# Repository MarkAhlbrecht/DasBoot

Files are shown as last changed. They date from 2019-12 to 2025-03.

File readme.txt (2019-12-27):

This directory is for data files
File Descriptions
S2_long_static - Sense Hat 2 Long Run with no motion at 30 deg (temp is tag 7)
heading_cal_test - Level with compass cal circles while temp rises throught self heating
heading_cal_test2 - Continuation of above after crash
S2_RotCal_1217 - Sense Hat 2 Rot Cal
	 (30 deg increment level swing)
         (pitch -30 +45 +90 with 45 deg level swing)
 	 (roll -30 +45 +90 with 45 deg level swing)
Heading_cal_log_up_near_drill_press - test effect of data collection near/far from magnet/drillpress
Heading_cal_log_power_up_near_magnet - This test is close to magnet.
plot1-5.pdf - plots from near/far magnet/drillpress test.

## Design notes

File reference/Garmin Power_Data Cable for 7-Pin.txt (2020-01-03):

Garmin Power/Data Cable for 7-Pin

GARMIN BOAT POWER DATA CABLE 010-10083-00 | 2 AMP 182 SERIES
Boat part number 1075154 is a new access power data cable for a 182 series Garmin fishfinder, part number 010-10083-00 .
Disclaimers & Restrictions
$17.95
MSRP: $23.51
GLS STOCK #: 1075154-5J572
22 IN STOCK

https://www.greatlakesskipper.com/garmin-boat-power-data-cable-010-10083-00-2-amp-182-series

Second option
Garmin Power/Data Cable for 7-Pin Chartplotters. Replacement part.
GAX10083    MAN#: 010-10083-00    ID#: 3194
Our Price: $23.95
Availability: In Stock
Condition: Brand New
Submit
Description
Garmin Power/Data Cable for 7-Pin Chartplotters. Replacement part. Works for the Fishfinder 320C, GBR 21, GPS 120, 
GPS 120XL, GPS 125 Sounder, GPS 126, GPS 128, GPS 152, GPS 152H, GPSMAP 130, GPSMAP 135 SOUNDER, GPSMAP 162, 
GPSMAP 175, GPSMAP 180, GPSMAP 182/182C, GPSMAP 192C, GPSMAP 205, GPSMAP 210, GPSMAP 215, GPSMAP 220, GPSMAP 225, 
GPSMAP 230, GPSMAP 232, GPSMAP 235 Sounder.

Website:
https://www.thegpsstore.com/Garmin-PowerData-Cable-for-7-Pin-Chartplotters-P3194.aspx

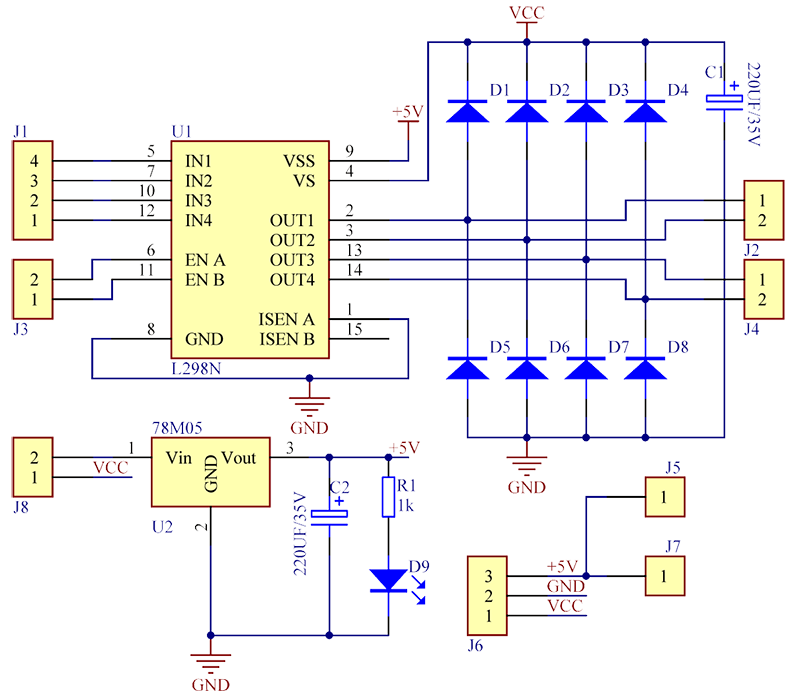
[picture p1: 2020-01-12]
reference/H_bridge_schematic.png

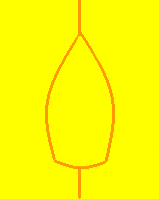
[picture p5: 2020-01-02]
code/python/resources/HeadingIndicator_Boat.png

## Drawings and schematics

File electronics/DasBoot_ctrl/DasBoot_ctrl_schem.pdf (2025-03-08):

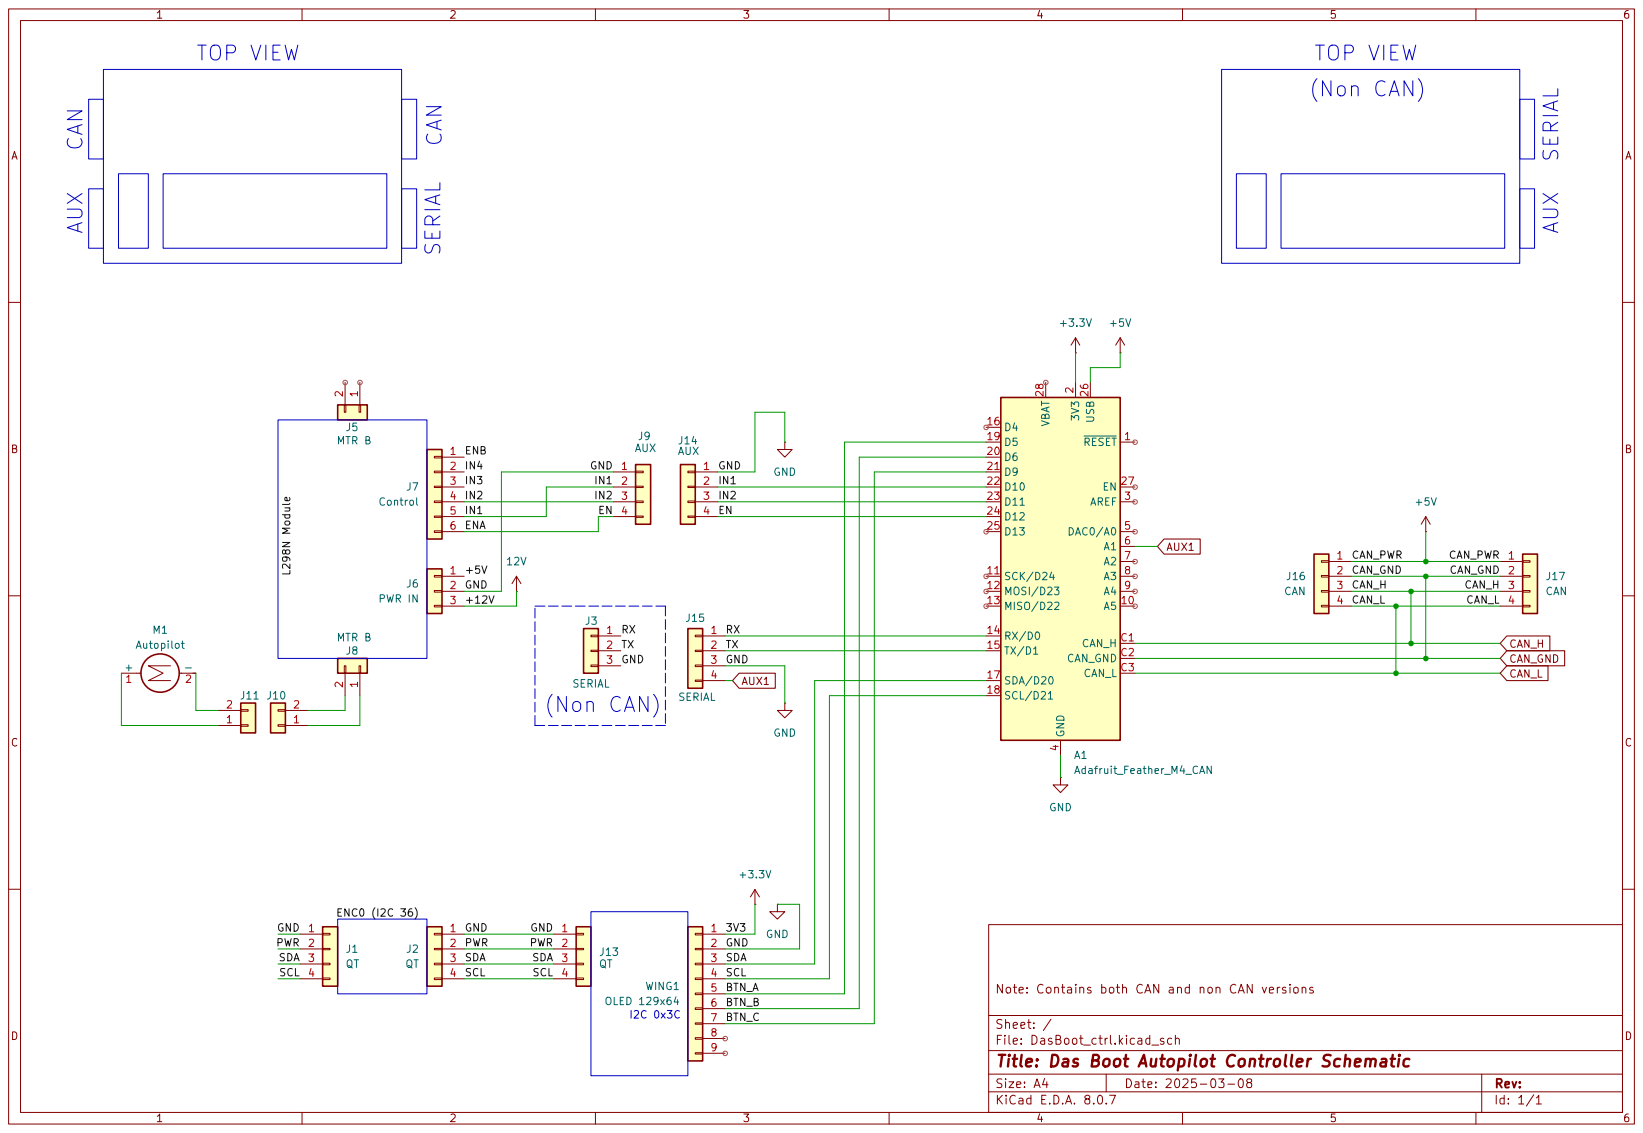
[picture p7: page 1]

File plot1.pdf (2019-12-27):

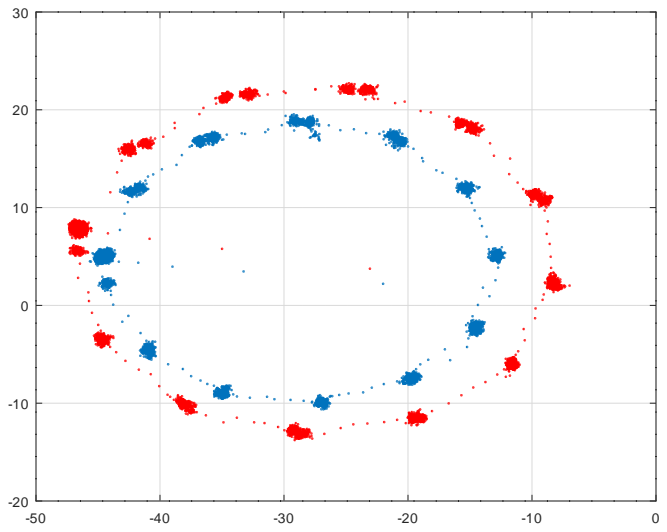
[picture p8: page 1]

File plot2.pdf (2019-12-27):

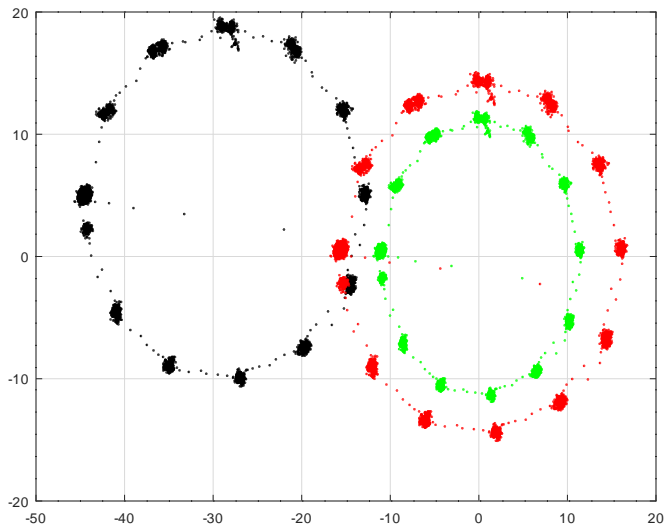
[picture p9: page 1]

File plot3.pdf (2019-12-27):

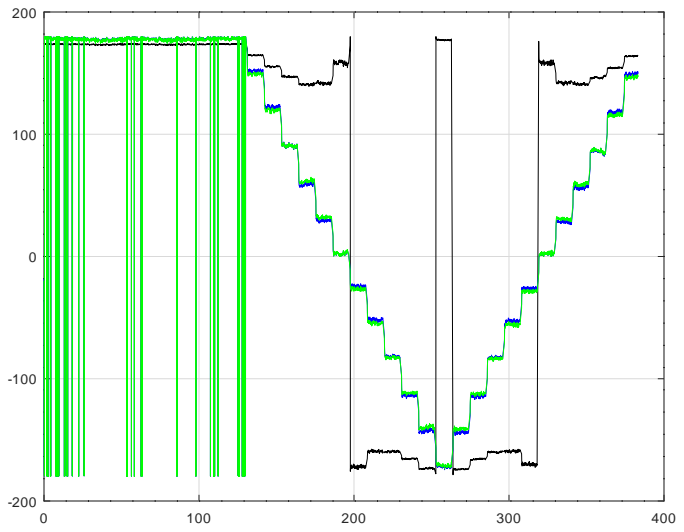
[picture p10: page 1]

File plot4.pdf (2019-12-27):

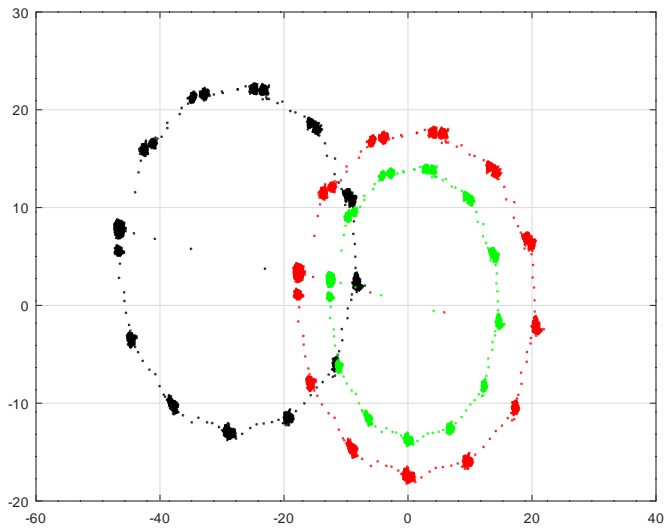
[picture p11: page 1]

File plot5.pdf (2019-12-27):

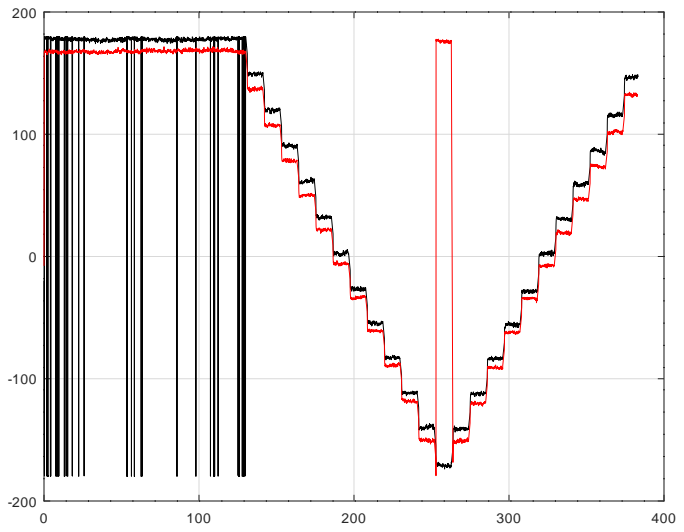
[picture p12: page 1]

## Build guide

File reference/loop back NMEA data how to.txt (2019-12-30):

1) Plug in USB breakout interface
	I needed this to get the NMEA simulator to recognize  a serial port.
2) Connect single jumper wire 
	from USB breakout interface Tx pin to Raspberry Pi Rx pin (GPIO 10)
3) Pi serial port should now be /dev/serial0
4) USB breakout interface should now be /dev/ttyUSB0
5) Run NMEA Simulator Chrome app
	to get: (https://chrome.google.com/webstore/detail/nmea-simulator/dfhcgoinjchfcfnnkecjpjcnknlipcll?hl=en)
	In Options -> settings
		select Server
			Set port to /dev/ttyUSB0
			I set Speed to 9600
			I set Data Bits to eight
			I set Parity Bits to no
			I set Stop Bits to one
		Save
	Select Start button.  You should see data changing on GUI
6) Now NMEA 0183 simulated serial data is streaming from /dev/ttyUSB0 into /dev/serial0
7) In Thonny, load simple_serial_with_pynmea4.py file.
	This file will open /dev/serial0 port and start reading lines.
	It looks for any "GGA" NMEA sentences
	When a GGA sentence is found, it parses it with pynmea2 and prints to Thonny shell
		Note: To get pynmea2 to run without error, I had to run:
			python3 -m pip install pynmea2
			This installed pynmea2 in the python3 path.

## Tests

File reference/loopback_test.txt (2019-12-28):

	Loopback test
	
	Steps I used to perform loopback on USB port of Raspberry Pi

1) Found USB breakout interface.  (Used from ESP-01 programmer)
	a) https://www.electroschematics.com/the-mighty-esp-01-adapter/
2) Shorted Tx to RX with jumper wire
3) On Pi
	a) Find what serial port are in use before plugging in USB loopback
	b) dmesg | grep tty.  This will show existing used tty ports.
	c) Now plug in usb breakout interface.  This can be done powered.
	d) dmesg | grep tty.  You should now see a new tty port being used.  I saw ttyUSB0
	e) install minicom.  sudo apt-get install minicom lsof
	e) invoke  minicom with -s option.  sudo minicom -s
		1) arrow down to select "serial port setup"
			i) select A - serial device
			ii) change /dev/ttyxxx to /dev/ttyUSB0 
			iii) cr
			iv) exit
		2) you are now in minicom and can see the port is ttyUSB0.
			i) start typing.  You should see your keys echoed on the screen.
			ii) CTRL -A Q, yes to exit.

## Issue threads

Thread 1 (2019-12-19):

Get input from speed log

billwallraff, 2019-12-19:
- [ ] Analyze log
- [ ] Design circuit
- [ ] Build circuit
- [ ] Test circuit
- [ ] Pi integration
- [ ] AP integration

billwallraff, 2019-12-19:
Mark, what is the speed log?  What is the interface? Do you have link to documentation or specs?

MarkAhlbrecht, 2019-12-19:
The log measures the speed through water.  There is a little paddle wheel
that goes into the water and spins based on the water going past it.  I
think there is a maget on one of the paddles.  There is a pair of wires t
j.g at go to the display which is just an analog meter.  There is no power
other than that from the sensor.  I would like to digitize it and send it
to the pi.  All the components are up at the boat

On Thu, Dec 19, 2019, 10:37 AM Bill Wallraff <notifications@github.com>
wrote:

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

Closed 2020-03-21.

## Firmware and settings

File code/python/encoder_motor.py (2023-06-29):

# Manual Motor Driver with encoder
import PWM_Motor
from time import sleep

import RPi.GPIO as GPIO
import time

GPIO.setmode(GPIO.BCM)
GPIO.setup(18, GPIO.IN,pull_up_down=GPIO.PUD_UP)
GPIO.setup(12, GPIO.IN,pull_up_down=GPIO.PUD_UP)
GPIO.setup(16, GPIO.IN,pull_up_down=GPIO.PUD_UP)
GPIO.setup(20, GPIO.IN,pull_up_down=GPIO.PUD_UP)

prevReset = True
prevBtn = True
prevEncA = True
prevEncB = True

resetH2L = False
btnH2L = False
encoderAH2L = False
encoderBH2L = False
frameCnt = 0
resetDBTime = 0
encoderCnt = 0
prevCntTime = 0
debounceTime = 0

motorDelayCnt = 0
motorPeriod = 25


motor = PWM_Motor.PWM_Motor(fwdGPIO=19, revGPIO=26, pwdGPIO=13, deadband=5, scaleFactor=1)

while True:
    time.sleep(0.01)
    frameCnt +=1
    resetBtn = GPIO.input(18)
    encoderBtn = GPIO.input(12)
    encoderA = GPIO.input(16)
    encoderB = GPIO.input(20)

    if (encoderA == False and prevEncA == True and encoderB == True and prevEncB == True):
        
        if (frameCnt > prevCntTime + debounceTime):
            encoderCnt += 1
            #print(encoderCnt)
            prevCntTime = frameCnt
            motorDelayCnt += motorPeriod
    if (encoderB == False and prevEncB == True and encoderA == True and prevEncA == True):
        if (frameCnt > prevCntTime + debounceTime):
            encoderCnt -= 1
            #print(encoderCnt)
            prevCntTime = frameCnt
            motorDelayCnt -= motorPeriod
    
    print(f"{encoderCnt} {motorDelayCnt}")
    if (not(motorDelayCnt == 0)):
        if(motorDelayCnt > 0):
            # run motor
            motor.drive(100)
            motorDelayCnt -=1
        if(motorDelayCnt < 0):
            motor.drive(-100)
            motorDelayCnt +=1
    else:
        motor.drive(0)
    prevReset = resetBtn
    prevEncA = encoderA
    prevEncB = encoderB
    
GPIO.cleanup()

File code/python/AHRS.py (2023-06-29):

import numpy as np
import time
import math
from math import cos, sin, radians, degrees, sqrt, atan2, asin
from IMU import IMU

class AHRS:   
    
    def __init__(self,AhrsIMU,timeInit=0,HW_ID=1):
        
#         print("AHRS Constructor")
        self.IMU = AhrsIMU
        self.rates = np.array([0.0,0.0,0.0])
        self.accel = np.array([0.0,0.0,0.0])
        self.mag = np.array([0.0,0.0,0.0])
        self.att = np.array([0.0,0.0,0.0])
        self.gyroBias = np.array([0.0,0.0,0.0])
        self.prevTime = 0
        self.tau = 1/10
        self.attTau = 1/10
        self.g = 9.81
        self.accumTheta = np.array([0, 0 , 0])
        
        self.HW_ID = HW_ID
        
        if timeInit>0:
            self.startTime = timeInit
        else:
            self.startTime = 0
            
        #print("initialized {0}".format(self.HW_ID))
       
    def warmup(self,warmUpSamples):
        print("Warming up ...")
        for i in range(1,warmUpSamples):
            (t,r,a,m) = self.IMU.sample()
            self.prevTime = t
        print("Warm up complete")
    
    def align(self, alignSamples=100):
        print("Aligning {0} Samples".format(alignSamples))
        for i in range(1,alignSamples+1):
            (self.sampleTime,self.gyroRaw,self.accelRaw,self.magRaw) = self.IMU.sample()
#             print(f"--- Align Sample {i}")
#             print("RawAccel: ", self.accelRaw)
#             print("RawGyro: ", self.gyroRaw)
#             print("RawMag: ", self.magRaw)
            self.prevTime = self.sampleTime
            
            self.accel = self.accel + \
               1/alignSamples*self.accelRaw
            self.rates = self.rates + \
               1/alignSamples*self.gyroRaw
            self.mag = self.mag + \
               1/alignSamples*self.magRaw
            
#             print("Accel: ", self.accel)
#             print("Gyro: ", self.rates)
#             print("Mag: ", self.mag)
        
        # Establish initial prich roll from averaged accel measures
        self.att[1] = asin(self.accel[0]/self.g)  # Pitch
        self.att[0] = -atan2(self.accelRaw[1],-self.accelRaw[2]) # Roll               
        Ca = self.euler2C(self.att[1],self.att[0],0.0)
        
#         print(np.degrees(self.att))
#         print(Ca)

        # Establish initial heading from horizontal mag measuremetns
        magL = Ca.dot(self.mag.transpose())
        self.att[2] = atan2(-1*magL[1],magL[0])

        # Initialize Gyro, Accel, and Filtered to Level transitions
        self.C_AL = self.euler2C(self.att[1],self.att[0],self.att[2])
        self.C_GL = self.euler2C(self.att[1],self.att[0],self.att[2])
        self.C_FL = self.euler2C(self.att[1],self.att[0],self.att[2])

        # Initial Gyro bias is the average over sample period
        self.gyroBias = self.rates
        self.gyroBias = np.array([0.0, 0.0, 0.0])
        print("Align Attitude:")
        print(self.att*degrees(1.0))
        print("Align Gyro Bias")
        print(self.gyroBias*degrees(1.0))
        self.prevTime = self.sampleTime - self.startTime

    """
    "   c2euler
    "   This routine converts a C matrix represention to euler representation
    "   Input: C matrix
    "   Output: pitch roll yaw
    """
    def euler2C(self,pitch,roll,yaw):
        C = np.zeros( (3,3) )
        cTheta = cos(pitch)
        sTheta = sin(pitch)
        cPhi = cos(roll)
        sPhi = sin(roll)
        cPsi = cos(yaw)
        sPsi = sin(yaw)
        C[0,0] = cTheta*cPsi
        C[0,1] = -1*cPhi*sPsi + sPhi*sTheta*cPsi
        C[0,2] = sPhi*sPsi + cPhi*sTheta*cPsi
        C[1,0] = cTheta*sPsi
        C[1,1] = cPhi*cPsi + sPhi*sTheta*sPsi
        C[1,2] = -sPhi*cPsi + cPhi*sTheta*sPsi
        C[2,0] = -sTheta
        C[2,1] = sPhi*cTheta
        C[2,2] = cPhi*cTheta
        return C

    """
    "   c2euler
    "   This routine converts a C matrix represention to euler representation
    "   Input: C matrix
    "   Output: pitch roll yaw
    """
    def c2euler(self,C):
        pitch = -1*asin(C[2,0])
        yaw = atan2(C[1,0],C[0,0])
        roll = atan2(C[2,1],C[2,2])
        return (pitch,roll,yaw)

    """
    "   ortho_norm
    "   This routine ortho normalizes a C matrix
    "   Input: C matrix
    "   Output: Ortho normed C matrix
    """
    def ortho_norm(self,C):
        x = C[:,0]
        y = C[:,1]
        z = C[:,2]
    
        e = x.transpose()
        e = e.dot(y)
        eScalar = e/2
    
        xOrtho = x - e*y
        yOrtho = y - e*x
        zOrtho = np.cross(xOrtho,yOrtho)
    
        xNorm = 0.5*(3 - xOrtho.transpose().dot(xOrtho))*xOrtho
        yNorm = 0.5*(3 - yOrtho.transpose().dot(yOrtho))*yOrtho
        zNorm = 0.5*(3 - zOrtho.transpose().dot(zOrtho))*zOrtho
    
        Con = np.column_stack( (xNorm,yNorm,zNorm) )
        return Con

    # Update the Attitude Solution
    def update(self):
        r180 = radians(180)
        nr180 = radians(-180)
        r360 = radians(360)

        deltaTheta = np.array([0, 0 , 0])
        
        omega = np.array( [0, 0, 0] )
        deltaC = np.ones( (3,3) )

        (self.sampleTime,self.gyroRaw,self.accelRaw,self.magRaw) = self.IMU.sample()
        
        self.elapsedTime = self.sampleTime - self.startTime
#         print("AHRS gyroRaw,{0},{1}".format(self.elapsedTime,self.gyroRaw)) # rad/sec
#         print("AHRS accelRaw,{0},{1}".format(self.elapsedTime,self.accelRaw)) # rad/sec
#         print("AHRS magRaw,{0},{1}".format(self.elapsedTime,self.magRaw)) # rad/sec
   
        deltaTime = self.elapsedTime - self.prevTime
  
        # Accumplate Rates
        omega = self.gyroRaw - self.gyroBias
        deltaTheta = omega*deltaTime # Basic Integration
        self.accumTheta = self.accumTheta + deltaTheta
#         print(f"DeltaT {deltaTime}")
#         print("Dt {0} {1} {2}".format(degrees(self.accumTheta[0]), \
#                                       degrees(self.accumTheta[1]), \
#                                       degrees(self.accumTheta[2])))

        # Form the deltaC matrix from the angular rotations
        # Single taylor series with small angle assumption
        deltaC[0,1] = -1*deltaTheta[2]
        deltaC[0,2] = deltaTheta[1]
        deltaC[1,0] = deltaTheta[2]
        deltaC[1,2] = -1*deltaTheta[0]
        deltaC[2,0] = -1*deltaTheta[1]
        deltaC[2,1] = deltaTheta[0]

       # Update the gyro and filter solution
        self.C_GL = self.C_GL.dot(deltaC)
#         (pf,rf,yf) = self.c2euler(self.C_GL)
#         print("=======================>C_GYRO: {0}".format(np.degrees(np.array([pf,rf,yf]))))
        
        
        self.C_FL = self.C_FL.dot(deltaC)
#        self.C_FL = self.ortho_norm(self.C_FL)
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

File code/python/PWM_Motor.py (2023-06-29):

import RPi.GPIO as GPIO

"""
DC Motor PWM Class
   m = PWM_Motor(fwdGPIO, revGPIO, pwdGPIO, deadband=0)
"""


class PWM_Motor:
    
    def __init__(self, fwdGPIO=11, revGPIO=12, pwdGPIO=7, deadband=0, scaleFactor=1):
        print(fwdGPIO)
        print(revGPIO)
        print(pwdGPIO)
        self.fwdGPIOPin = fwdGPIO
        self.revGPIOPin = revGPIO
        self.pwdGPIOPin = pwdGPIO
        self.deadband = deadband
        self.scaleFactor = scaleFactor

        # Set mode of GPIO to BOARD
        # Note - This should be checked for conflict at some point
        GPIO.setmode(GPIO.BCM)

        GPIO.setup(self.fwdGPIOPin, GPIO.OUT)
        GPIO.setup(self.revGPIOPin, GPIO.OUT)
        GPIO.setup(self.pwdGPIOPin, GPIO.OUT)
        self.pwm=GPIO.PWM(self.pwdGPIOPin, 100)
        self.pwm.start(0)
        self.forward = 0
        self.reverse = 0
        self.motorPwm = 0
        self.pwm.ChangeDutyCycle(100)
        GPIO.output(self.pwdGPIOPin, True)
        GPIO.output(self.fwdGPIOPin, self.forward)
        GPIO.output(self.revGPIOPin, self.reverse)
        self.pwm.ChangeDutyCycle(self.motorPwm)

    def drive(self,throttle):
 
        if abs(throttle) > self.deadband:
            self.forward = (throttle >= 0)
            self.reverse = (not self.forward)
            self.motorPwm = abs(self.scaleFactor*throttle)
            if self.motorPwm > 100:
                self.motorPwm = 100
        else:
            self.forward = False
            self.reverse = False
            self.motorPwm = 0
            #
            # Command Motor Pins
            #
        
        GPIO.output(self.fwdGPIOPin, self.forward)
        GPIO.output(self.revGPIOPin, self.reverse)
        self.pwm.ChangeDutyCycle(self.motorPwm)
        return (self.forward,self.reverse,self.motorPwm)
    
    def close(self):
        self.drive(0)
        GPIO.output(self.pwdGPIOPin, False)
        self.pwm.stop()
        GPIO.cleanup()

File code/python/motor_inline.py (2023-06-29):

import RPi.GPIO as GPIO
from time import sleep

#PWM_PIN = 33
#FWD_PIN = 35
#REV_PIN = 37
PWM_PIN = 13
FWD_PIN = 19
REV_PIN = 26

GPIO.setmode(GPIO.BCM)

GPIO.setup(FWD_PIN, GPIO.OUT)
GPIO.setup(REV_PIN, GPIO.OUT)
GPIO.setup(PWM_PIN, GPIO.OUT)

pwm=GPIO.PWM(PWM_PIN, 100)
pwm.start(0)
pwm.ChangeDutyCycle(100)
GPIO.output(PWM_PIN, True)

# CW at full speed
print ("CW at full speed")
GPIO.output(FWD_PIN, True)
GPIO.output(REV_PIN, False)
sleep(2)

# CCW at full speed
print("CCW at full speed")
GPIO.output(REV_PIN, True)
GPIO.output(FWD_PIN, False)
sleep(2)

# change to 50% speed
print("set speed to 50%")
pwm.ChangeDutyCycle(50)
GPIO.output(PWM_PIN, True)

# CW at 50% speed
print("CW at 50% speed")
GPIO.output(FWD_PIN, True)
GPIO.output(REV_PIN, False)
sleep(2)

# CCW at 50% speed
print("CCW at 50% speed")
GPIO.output(REV_PIN, True)
GPIO.output(FWD_PIN, False)
sleep(2)

# change to 25% speed
print("set speed to 25%")
pwm.ChangeDutyCycle(25)
GPIO.output(PWM_PIN, True)

# CW at 25% speed
print("CW at 25% speed")
GPIO.output(FWD_PIN, True)
GPIO.output(REV_PIN, False)
sleep(2)

# CCW at 25% speed
print("CCW at 25% speed")
GPIO.output(REV_PIN, True)
GPIO.output(FWD_PIN, False)
sleep(2)

# change to 15% speed
print("set speed to 15%")
pwm.ChangeDutyCycle(15)
GPIO.output(PWM_PIN, True)

# CW at 15% speed
print("CW at 15% speed")
GPIO.output(FWD_PIN, True)
GPIO.output(REV_PIN, False)
sleep(2)

# CCW at 15% speed
print("CCW at 15% speed")
GPIO.output(REV_PIN, True)
GPIO.output(FWD_PIN, False)
sleep(2)

GPIO.output(PWM_PIN, False)

pwm.stop()

GPIO.cleanup()

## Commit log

2019-12-18 Created Sense2 Cal Files
    [heading_tcal_test2.csv]
2019-12-18 Data Reduction and Analysis of long run and Rot Cal
    [heading_tcal_test2.csv]
2019-12-26 Test Hard Iron at power up
    One file is data after power up, near (1ft) the drill press. Second file is data after power up, 3.5 ft from drill press and 2 ft from magnets
    [Heading_cal_log_power_up_near magnet.csv]
2019-12-26 test hard Iron at power up
    This file is data after power up, but near (1ft) drill press. was 7th from magnet.
    [Heading_cal_log_up_near_drill_press.csv]
2019-12-27 magnet/drillprees test
2020-01-02 Updated calibrator to use motor
2020-01-02 Change from heading test
    [calibrate_raw.csv, heading_ctrl_test.csv]
2020-01-03 GPSmap 135 mating connector
2020-01-03 Garmin 7-pin connector
2020-01-12 schematic for Adafruit 2.2 display
2020-01-12 Sense HAT schematic
2020-01-12 Pin conflicts with Sense HAT and Adafruit 2.2 display
    [pi_gpio_HAT_conflict.xls]
2020-01-17 Updates for Sense2
    [calibrate_raw.csv, heading_ctrl_test.csv]
2020-01-17 Updated for dial OOP and started motor class
    [heading_ctrl_test.csv]
2020-01-17 Motor Class updates
2020-01-20 More OOP Updates
    [calibrate_raw.csv, heading_ctrl_test.csv]
2020-01-22 AHRS OOP Updates
    [calibrate_raw.csv]
2020-02-26 updated conflict file
    [pi_gpio_HAT_conflict_v2.xls]
2020-03-20 USB cable wire colors
2020-06-22 Updates for Boat Test
    [calibrate_raw.csv, heading_ctrl_test.csv]
2020-11-11 Nov10 Update
    [calibrate_raw.csv, heading_ctrl_test.csv]
2021-07-25 Add files via upload
    Updated for new IMU
2025-03-08 Added Schematic
    [DasBoot_ctrl.kicad_pcb, DasBoot_ctrl.kicad_sch]
2026-02-20 add boat records
    [3k.csv, 4k.csv, 5k.csv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]
